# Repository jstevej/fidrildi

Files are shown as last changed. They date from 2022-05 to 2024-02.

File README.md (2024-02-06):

# Fiðrildi

Fiðrildi is a 34-key, ortholinear, butterfly-shaped, unibody split keyboard inspired by [Reviung](https://github.com/gtips/reviung), [Corne](https://github.com/foostan/crkbd), and others.

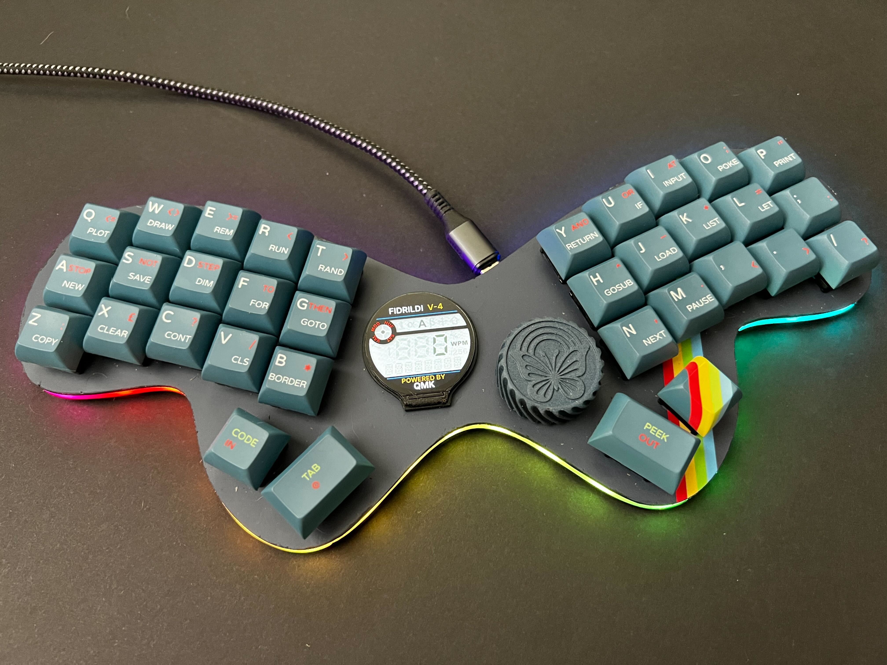
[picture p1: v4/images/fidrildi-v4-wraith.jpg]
Picture of Fiðrildi Keyboard

Picture of Fiðrildi Keyboard

QMK support is in the ["steve" branch of my QMK repo](https://github.com/jstevej/qmk_firmware/tree/steve)

I use my own [custom keymap](https://github.com/jstevej/steves-keyboard-layout) on these, which is also in my QMK branch.

Versions:

- [Version 4](https://github.com/jstevej/fidrildi/tree/main/v4): Based on version 3 with bug fixes and ergonomic tweaks. Keeps the reverse-mount LEDs and acrylic, removes the 4-pin JST connector, adds rotary encoder. MCU is soldered in rather than socketed in order to minimize the profile. Requires [0xcb Helios](https://github.com/0xCB-dev/0xCB-Helios) MCU.
- [Version 3](https://github.com/jstevej/fidrildi/tree/main/v3): Ergonomic tweaks, peripheral support via 4-pin and 8-pin JST SH (1 mm) connectors, switch to reverse-mount LEDs and acrylic middle layer. MCU is soldered in rather than socketed in order to minimize the profile. Requires [0xcb Helios](https://github.com/0xCB-dev/0xCB-Helios) MCU.
- [Version 2](https://github.com/jstevej/fidrildi/tree/main/v2): Eronomic tweaks, Cirque trackpad, GC9A01 display, rotary encoder, and side-mount LEDs on the bottom of the PCB. MCU is soldered in rather than socketed in order to minimize the profile. Requires [0xcb Helios](https://github.com/0xCB-dev/0xCB-Helios) MCU.
- [Version 1](https://github.com/jstevej/fidrildi/tree/main/v1): Inspired by the [MT3 Lord of the Rings keycaps](https://matt3o.com/the-tolkien-keycaps-are-finally-live/).

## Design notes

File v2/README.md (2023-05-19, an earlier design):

# Fiðrildi 2

Fiðrildi 2 is a 34-key, ortholinear, butterfly-shaped, unibody split keyboard inspired by [Reviung](https://github.com/gtips/reviung), [Corne](https://github.com/foostan/crkbd), and others.

It is designed specifically for the [0xcb Helios](https://github.com/0xCB-dev/0xCB-Helios), and uses all available pins. The Helios is soldered in to minimize the profile so that it can be sandwiched between the top plate and bottom PCB.

The PCB has 40 side-mounted SK6812-SIDE LEDs that shine horizontally outward from the underside of the PCB.

Supports a Cirque trackpad, an EC11-style encoder, and a GC9A01 display. There are FPC and JST SH (1mm) connectors on the top of the PCB for connecting these (or other) peripherals.

The column stagger is more exaggerated than the Corne, and the halves are tilted 5 degrees more than the Reviung.

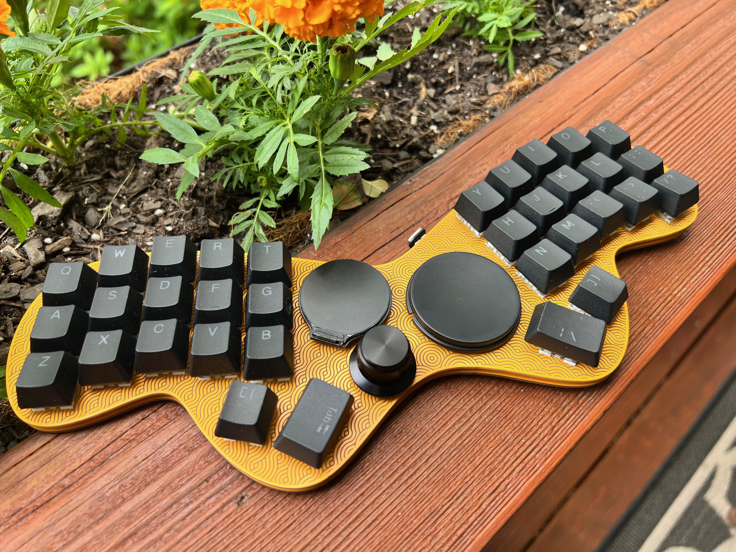
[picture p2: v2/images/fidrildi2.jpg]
Picture of Fiðrildi 2 Keyboard


## Issues with Version 2.0

  - The side-mounted LEDs are very difficult to work with, and the horizontal lighting effect is not worth the effort of dealing with them.

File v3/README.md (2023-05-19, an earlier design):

# Fiðrildi 3

Fiðrildi 3 is a 34-key, ortholinear, butterfly-shaped, unibody split keyboard inspired by [Reviung](https://github.com/gtips/reviung), [Corne](https://github.com/foostan/crkbd), and others.

It is designed specifically for the [0xcb Helios](https://github.com/0xCB-dev/0xCB-Helios), and uses all available pins. The Helios is soldered in to minimize the profile so that it can be sandwiched between the top plate and bottom PCB.

The top plate is a PCB with artwork done on the soldermask layer so that it is silver. The artwork is duplicated on the back in silkscreen in case that aesthetic is preferable.

The PCB has 40 reverse-mounted SK6812-E LEDs that shine upwards through slots in the PCB. These illuminate an acrylic middle-layer from below and are visible at its edge.

There are 4-pin and 8-pin JST SH (1 mm) connectors on the top of the PCB for connecting extras (LCD, Cirque, etc.).

The column stagger is more exaggerated than the Corne, and the halves are tilted 8 degrees more than the Reviung.

Picture of Fiðrildi 3 Keyboard
Picture of Fiðrildi 3 Keyboard
Picture of Underside of Fiðrildi 3 Keyboard

## Issues with Version 3.0

  - "EXT5/10" silkscreen on J2 and J3 incorrect; should be "EXT5/14"
  - LED bottom silkscreen labels reversed
  - J1 pins can't be assigned for I2C0 or I2C1

## Improvements for Next Version

  - Fix issues described above.
  - Would be nice if LEDs could be set even further in from edge. It should make the edge light more uniform. Also, they shine through the side of the bottom PCB.
  - Add encoder footprints to bottom PCB?
  - Add GC9A01 cutout to top plate?

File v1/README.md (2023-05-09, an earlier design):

# Fiðrildi

Fiðrildi is a 34-key, ortholinear, butterfly-shaped, unibody split keyboard inspired by [Reviung](https://github.com/gtips/reviung), [Corne](https://github.com/foostan/crkbd), and the [Lord of the Rings Elvish keycaps](https://matt3o.com/the-tolkien-keycaps-are-finally-live/).

The column stagger is just slightly more exaggerated than the Corne, and the halves are tilted 2 degrees more than the Reviung.

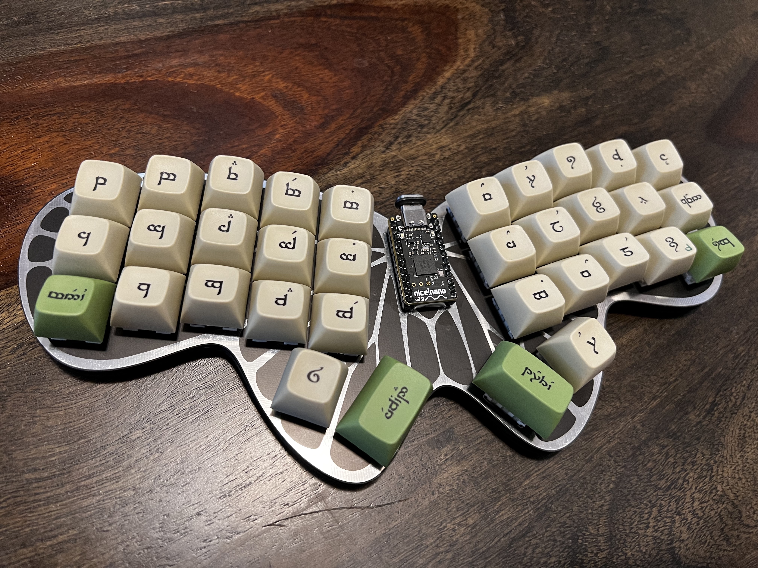
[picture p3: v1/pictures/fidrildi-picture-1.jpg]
Picture of Fiðrildi Keyboard


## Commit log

2022-05-22 Initial commit of Fiðrildi version 0.1.
    [fidrildi.kicad_pcb, fidrildi.kicad_sch]
2023-05-09 Merged all fidrildi versions into one primary repository.
    [fidrildi.kicad_pcb, fidrildi.kicad_sch, fidrildi2.kicad_pcb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]
2023-08-26 Added Fidrildi v4.
    [fidrildi4-B_Cu.gbl, fidrildi4-B_Mask.gbs, fidrildi4-B_Paste.gbp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]
